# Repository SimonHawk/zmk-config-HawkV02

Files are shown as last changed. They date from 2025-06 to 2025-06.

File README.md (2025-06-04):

# HawkV0 keyboard
The HawkV02 (Hardware revision 0, firmware revision 2) is my first keyboard design. It is a 56 key fully wireless split keyboard (4x6 + 4 thumb keys for each half), made to use nice!nano microcontrollers (or clones). The PCB is flippable, so you just need two of the same PCB to have a full split keyboard.

The repository is under construction! 

## Ergogen and PCB files:
The ergogen configuration can be found in "ergogen/config_HawkV0_prod.yaml", the required footprint files in "ergogen/footprints". The ergogen output can be found in "ergogen/HawkV0_output_prod", and in the handrouted PCB can be found in "ergogen/HawkV0_output_prod/pcbs/KeyboardV0.kicad_pcb". I think the "ergogen/HawkV0_output_prod/pcbs/KeyboardV0_gerbes.zip" file should be ready to upload to a PCB manufacturer, I used jlcpcb.com with good results.

## Credit
This repository is a fork of the bug54 repository by ogruendel, because I want to start with a working ZMK configuration and modify it to my needs. Big thanks to ogruendel for making it all availible!

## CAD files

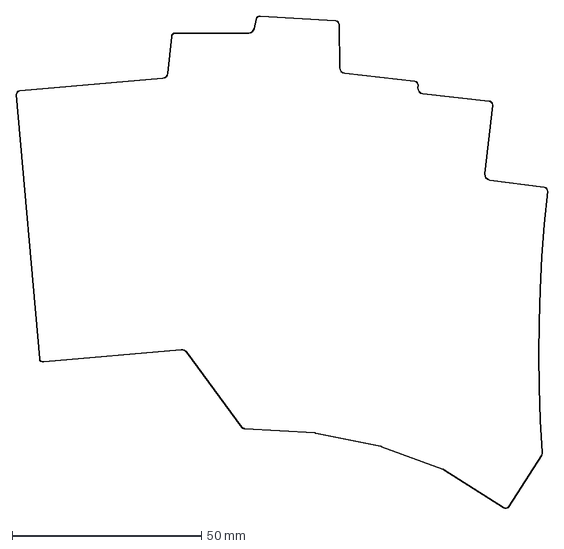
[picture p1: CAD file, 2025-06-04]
ergogen/HawkV0_output_prod/outlines/board.dxf
140.6 x 130.3 mm

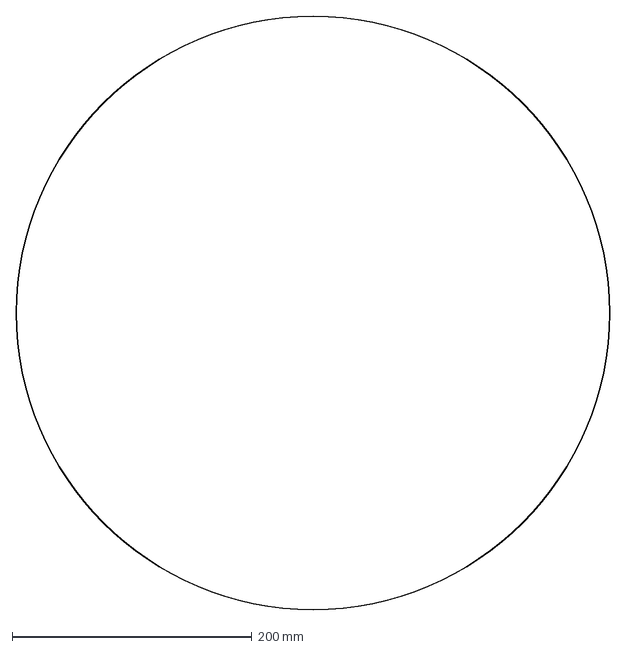
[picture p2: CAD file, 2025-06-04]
ergogen/HawkV0_output_prod/outlines/cutout_circle_right_wall.dxf
495.0 x 495.0 mm

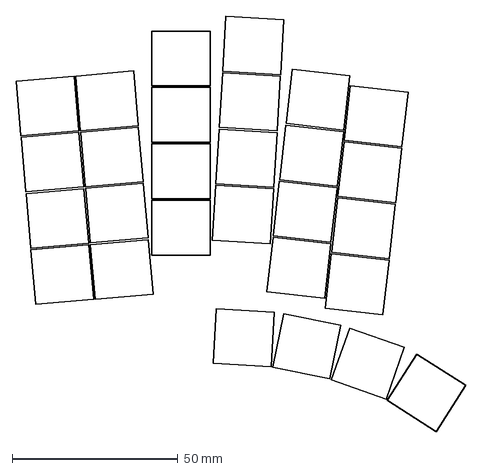
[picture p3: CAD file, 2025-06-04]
ergogen/HawkV0_output_prod/outlines/keys.dxf
135.5 x 125.1 mm

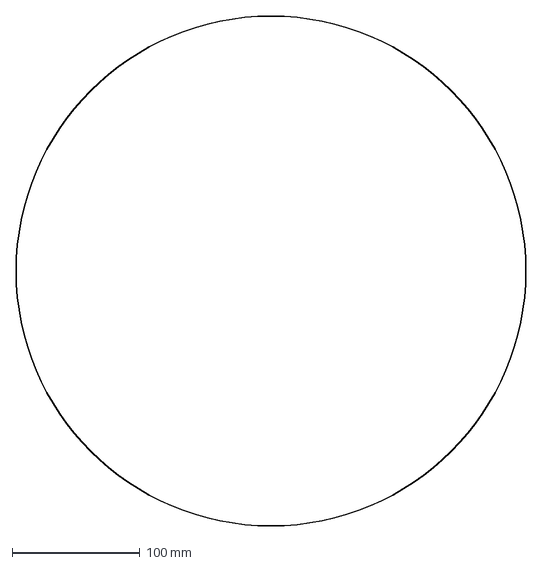
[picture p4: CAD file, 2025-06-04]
ergogen/HawkV0_output_prod/outlines/cutout_circle_thumb_inner_wall.dxf
399.0 x 399.0 mm

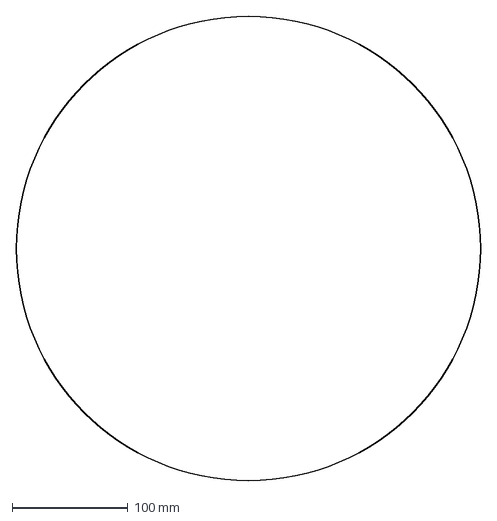
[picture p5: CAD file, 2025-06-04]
ergogen/HawkV0_output_prod/outlines/cutout_circle_thumb_inner_inner_wall.dxf
400.8 x 400.8 mm

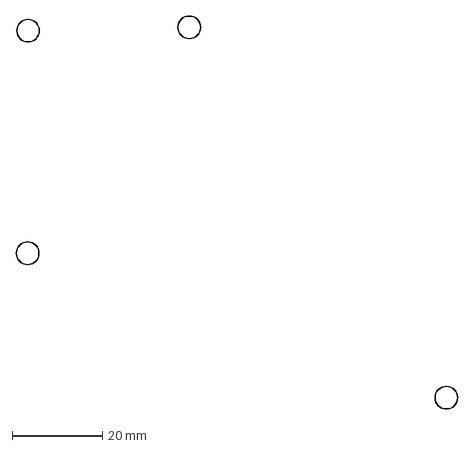
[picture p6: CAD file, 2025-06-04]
ergogen/HawkV0_output_prod/outlines/standoff.dxf
97.9 x 87.2 mm

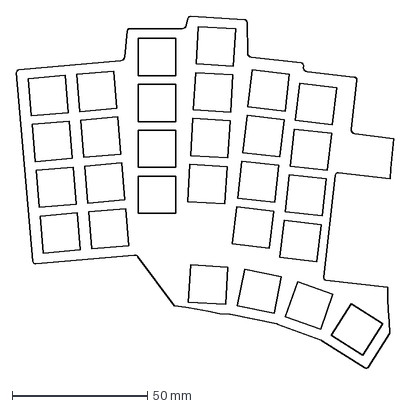
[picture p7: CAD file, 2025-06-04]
ergogen/HawkV0_output_prod/outlines/plate.dxf
139.6 x 130.3 mm

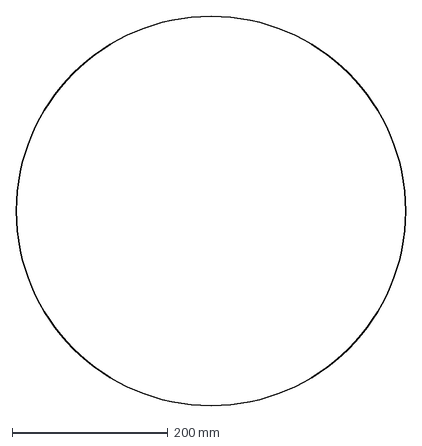
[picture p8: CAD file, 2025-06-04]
ergogen/HawkV0_output_prod/outlines/cutout_circle_right_inner_inner_wall.dxf
500.8 x 500.8 mm

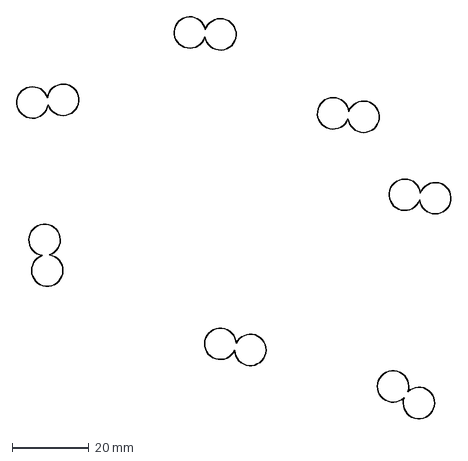
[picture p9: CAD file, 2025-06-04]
ergogen/HawkV0_output_prod/outlines/feetholes.dxf
113.7 x 105.5 mm

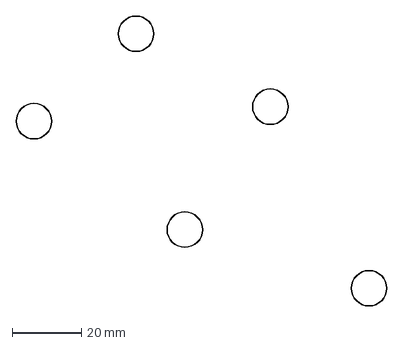
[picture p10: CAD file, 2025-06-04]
ergogen/HawkV0_output_prod/outlines/magnetholes.dxf
106.7 x 83.5 mm

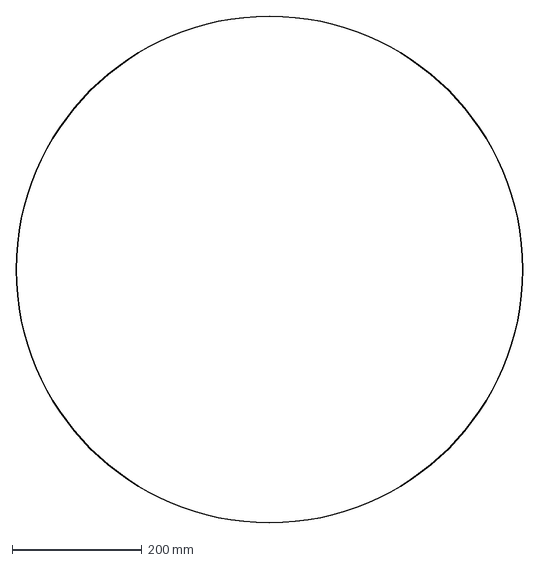
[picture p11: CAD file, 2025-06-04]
ergogen/HawkV0_output_prod/outlines/cutout_circle_right.dxf
780.0 x 780.0 mm

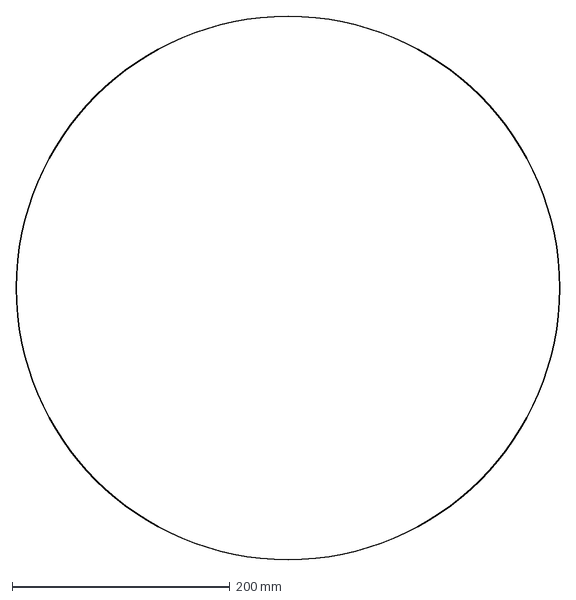
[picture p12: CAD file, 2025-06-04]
ergogen/HawkV0_output_prod/outlines/cutout_circle_right_inner_wall.dxf
499.0 x 499.0 mm

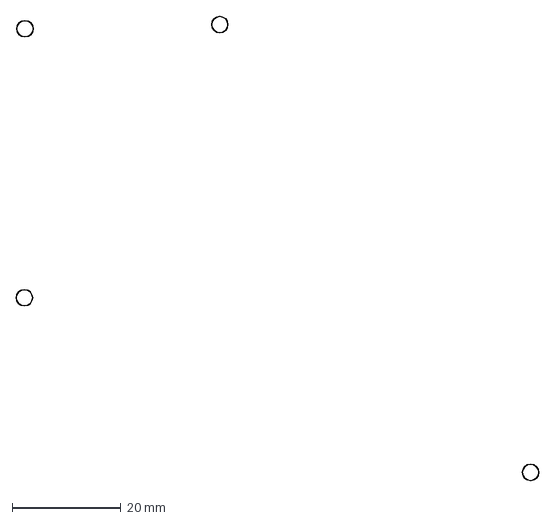
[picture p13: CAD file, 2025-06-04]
ergogen/HawkV0_output_prod/outlines/mounting.dxf
95.9 x 85.2 mm

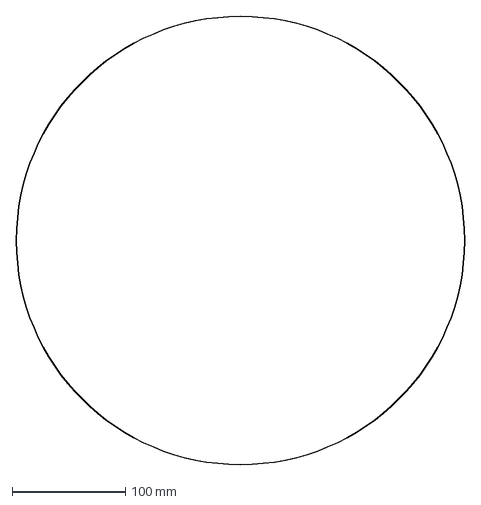
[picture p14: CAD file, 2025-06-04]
ergogen/HawkV0_output_prod/outlines/cutout_circle_thumb_wall.dxf
395.0 x 395.0 mm

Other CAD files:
ergogen/HawkV0_output_prod/outlines/switches.dxf
ergogen/HawkV0_output_prod/outlines/cutout_circle_thumb.dxf
ergogen/HawkV0_output_prod/outlines/plate_test.dxf

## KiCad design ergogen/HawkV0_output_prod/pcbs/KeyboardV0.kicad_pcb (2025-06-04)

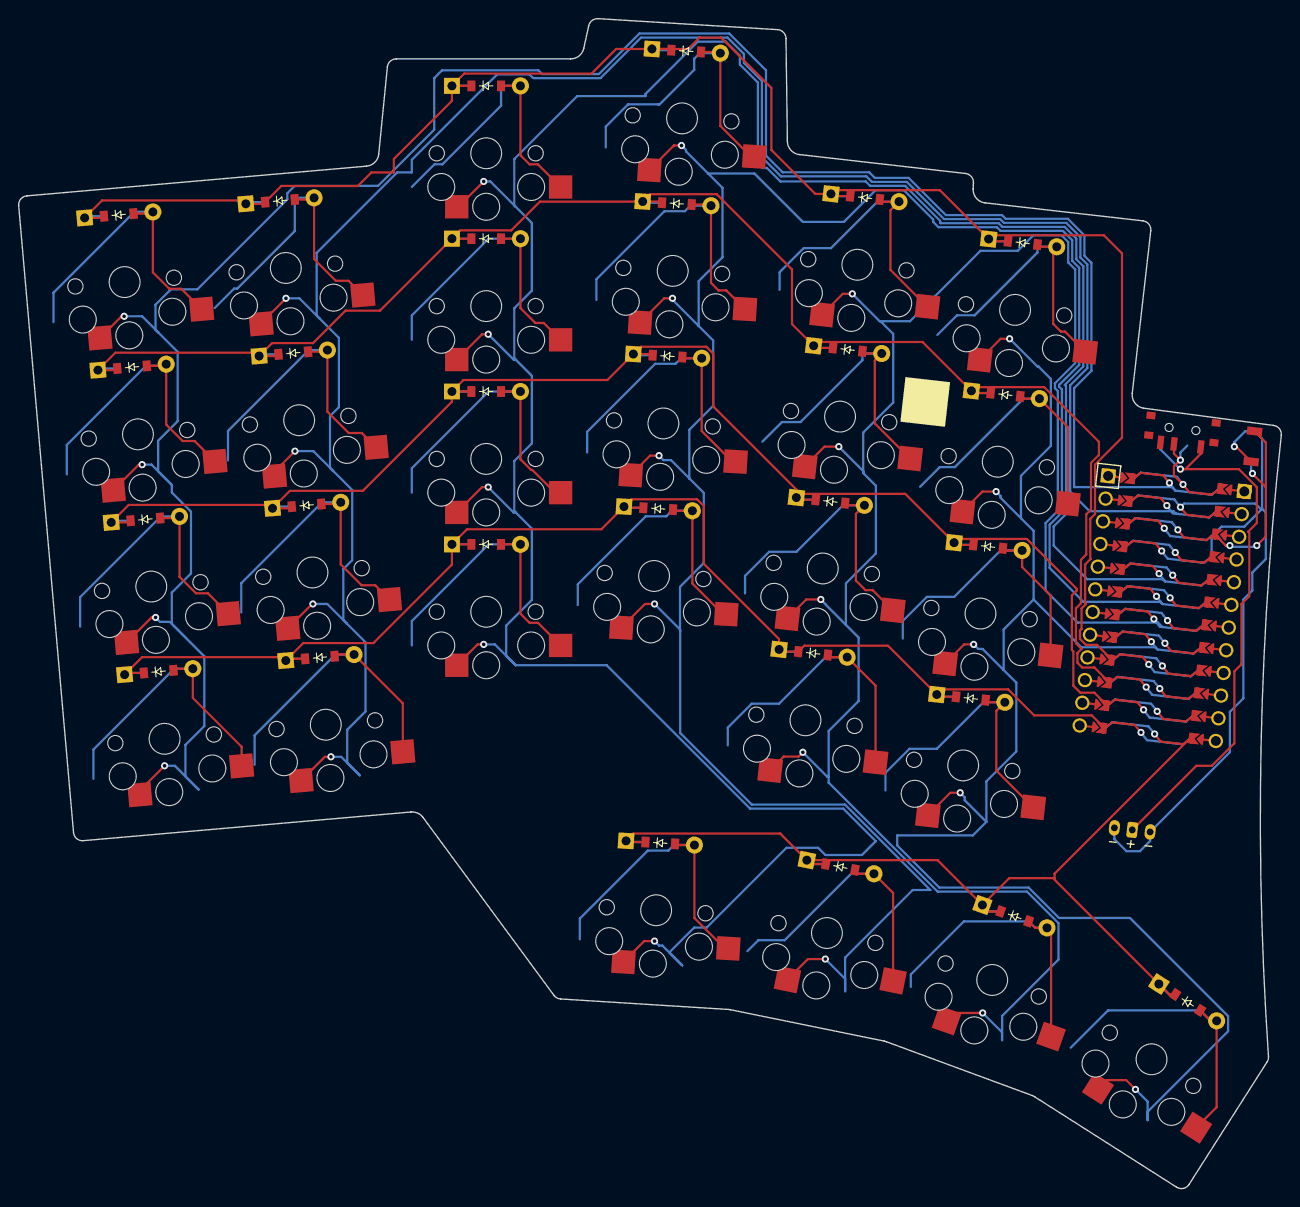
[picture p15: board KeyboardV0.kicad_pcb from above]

Board: 2 copper layers, 140.5 x 130.1 mm, 58 parts (0 on the bottom side), 40 nets.

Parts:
D1, D2, D3, D4, D5, D6, D7, D8, D9, D10, D11, D12, D13, D14, D15, D16, D17, D18, D19, D20, D21, D22, D23, D24, D25, D26, D27, D28: ComboDiode
MCU1: ProMicro
S1, S2, S3, S4, S5, S6, S7, S8, S9, S10, S11, S12, S13, S14, S15, S16, S17, S18, S19, S20, S21, S22, S23, S24, S25, S26, S27, S28: PG1350
_3: JST_PH_S2B-PH-K_1x02_P2.00mm_Horizontal

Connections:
GND: MCU1.2, MCU1.21, MCU1.22, _3.2, _3.3
P0: MCU1.23, S5.1, S6.1, S7.1, S8.1
P1: MCU1.24, S1.1, S2.1, S3.1, S4.1
P2: MCU1.20, S9.1, S10.1, S11.1, S12.1, S25.1
P3: MCU1.19, S13.1, S14.1, S15.1, S16.1, S26.1
P4: MCU1.18, S17.1, S18.1, S19.1, S20.1, S27.1
P5: MCU1.17, S21.1, S22.1, S23.1, S24.1, S28.1
P6: D4.1, D8.1, D12.1, D16.1, D20.1, D24.1, MCU1.16
P7: D3.1, D7.1, D11.1, D15.1, D19.1, D23.1, MCU1.15
P8: D2.1, D6.1, D10.1, D14.1, D18.1, D22.1, MCU1.14
P9: D1.1, D5.1, D9.1, D13.1, D17.1, D21.1, MCU1.13
P10: D25.1, D26.1, D27.1, D28.1, MCU1.12
center_cluster: D27.2, S27.2
index_bottom: D17.2, S17.2
index_home: D18.2, S18.2
index_num: D20.2, S20.2
index_top: D19.2, S19.2
inner_bottom: D21.2, S21.2
inner_cluster: D26.2, S26.2
inner_home: D22.2, S22.2
inner_num: D24.2, S24.2
inner_top: D23.2, S23.2
middle_bottom: D13.2, S13.2
middle_home: D14.2, S14.2
middle_num: D16.2, S16.2
middle_top: D15.2, S15.2
outer_bottom: D1.2, S1.2
outer_cluster: D28.2, S28.2
outer_home: D2.2, S2.2
outer_num: D4.2, S4.2
outer_top: D3.2, S3.2
pinky_bottom: D5.2, S5.2
pinky_home: D6.2, S6.2
pinky_num: D8.2, S8.2
pinky_top: D7.2, S7.2
ring_bottom: D9.2, S9.2
ring_home: D10.2, S10.2
ring_num: D12.2, S12.2
ring_top: D11.2, S11.2
tuck_cluster: D25.2, S25.2

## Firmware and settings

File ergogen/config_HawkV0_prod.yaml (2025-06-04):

units:
  kx: cx
  ky: cy

  pd: 2
  px: kx + pd
  py: ky + pd

  wpd: 2.5
  short_wpd: 0.5
  inner_wpd: -0.4

  # M2 screws
  screwsize: 1.5
  standoffsize: 2.5

  choc: 13.8

points:
  zones:
    matrix:
      # Fix placement on KiCAD sheet.
      anchor:
        shift: [150, -150]
      key:
        padding: 1ky
        spread: 1kx
      columns:
        outer:
          key:
            splay: 5
          key.column_net: P1
        pinky:
          key.column_net: P0
        ring:
          key:
            stagger: 11
            splay: -5
            origin: [0, -ky+7]
          key.column_net: P2
        middle:
          key:
            stagger: 4
            splay: -3.5
            origin: [0, -ky+6]
          key.column_net: P3
        index:
          key:
            stagger: -15
            splay: -3
            origin: [0, -ky+21]
          key.column_net: P4
        inner:
          key:
            stagger: -3
          key.column_net: P5
      rows:
        bottom:
          row_net: P9
        home:
          row_net: P8
        top:
          row_net: P7
        num:
          row_net: P6
    thumbs:
      key: 
        padding: 1ky
        spread: 1kx
      anchor:
        ref: matrix_middle_bottom
        shift: [kx/4-2,-ky*2-3.1]
        rotate: 5
      columns:
        tuck:
          key:
            splay: -5
            #shift: [-2,2]
            column_net: P2
        inner:
          key:
            splay: -8
            shift: [1.3, -1.2]
            column_net: P3
        center:
          key:
            splay: -8
            shift: [2.7, -2.3]
            #origin: [-9, -9.5]
            column_net: P4
        outer:
          key:
            splay: -13
            shift: [5.3, -3.6]
            #origin: [-9, -9.5]
            column_net: P5
      rows:
        cluster:
          row_net: P10

    #thumbs2:
    #  key: 
    #    padding: 1ky
    #    spread: 1kx
    #  anchor:
    #    ref: matrix_middle_bottom
    #    shift: [kx/4-4,-ky*2-2]
    #    rotate: 5
    #  columns:
    #    tuck:
    #      key:
    #        splay: -5
    #        #shift: [-2,2]
    #        column_net: P2
    #    inner:
    #      key:
    #        splay: -8
    #        shift: [2, -1.8]
    #        column_net: P3
    #    center:
    #      key:
    #        splay: -8
    #        shift: [4.5, -2.9]
    #        #origin: [-9, -9.5]
    #        column_net: P4
    #    outer:
    #      key:
    #        splay: -13
    #        shift: [7.4, -3.8]
    #        #origin: [-9, -9.5]
    #        column_net: P5
    #  rows:
    #    cluster:
    #      row_net: P10

outlines:
  keys:
    - what: rectangle
      where: true
      bound: false
      size: [kx-0.5, ky-0.5]
  switches:
    - what: rectangle
      where: true
      bound: false
      size: [choc, choc]

  cutout_circle_thumb:
    - what: circle
      radius: 200
      where:
        ref: thumbs_inner_cluster
        shift: [-16, -211]
  cutout_circle_thumb_wall:
    - what: circle
      radius: 200-wpd
      where:
        ref: thumbs_inner_cluster
        shift: [-16, -211]
  cutout_circle_thumb_inner_wall:
    - what: circle
      radius: 200-short_wpd
      where:
        ref: thumbs_inner_cluster
        shift: [-16, -211]
  cutout_circle_thumb_inner_inner_wall:
    - what: circle
      radius: 200-inner_wpd
      where:
        ref: thumbs_inner_cluster
        shift: [-16, -211]

  cutout_circle_right:
    - what: circle
      radius: 390
      where:
        ref: matrix_inner_num
        shift: [420, -0.5kx]
  cutout_circle_right_wall:
    - what: circle
      radius: 250-wpd
      where:
        ref: matrix_inner_bottom
        shift: [281, 27]
  cutout_circle_right_inner_wall:
    - what: circle
      radius: 250-short_wpd
      where:
        ref: matrix_inner_bottom
        shift: [281, 27]
  cutout_circle_right_inner_inner_wall:
    - what: circle
      radius: 250-inner_wpd
      where:
        ref: matrix_inner_bottom
        shift: [281, 27]

  board:
    keyOutline:
      what: polygon
      operation: stack
      points:
        - ref: matrix_outer_num
          shift: [-0.5px, 0.5py]
        - ref: matrix_outer_bottom
          shift: [-0.5px, -0.5py]
        - ref: matrix_pinky_bottom
          shift: [0.5px, -0.5py]
        - ref: thumbs_tuck_cluster
          shift: [-0.5px, -0.5py]
        - ref: thumbs_inner_cluster
          shift: [-0.5kx, -0.5py]
          #shift: [-1px, -0.585py]
        - ref: thumbs_center_cluster
          shift: [-0.5kx, -0.47px]
        - ref: thumbs_outer_cluster
          shift: [-0.45px, -0.5py]
        - ref: thumbs_outer_cluster
          shift: [0.5px, -0.5py]
        - ref: thumbs_outer_cluster
          shift: [0.5px, 0.5py]

        - ref: matrix_inner_num
          affect: r
        - shift: [-0.2px, 3.53py-0.7]
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

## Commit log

2025-06-04 First commit to see if the firmware builds
    [Case.FCStd]
2025-06-04 Added ergogen and PCB files
    [KeyboardV0-B_Cu.gbr, KeyboardV0-B_Mask.gbr, KeyboardV0-B_Paste.gbr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]
